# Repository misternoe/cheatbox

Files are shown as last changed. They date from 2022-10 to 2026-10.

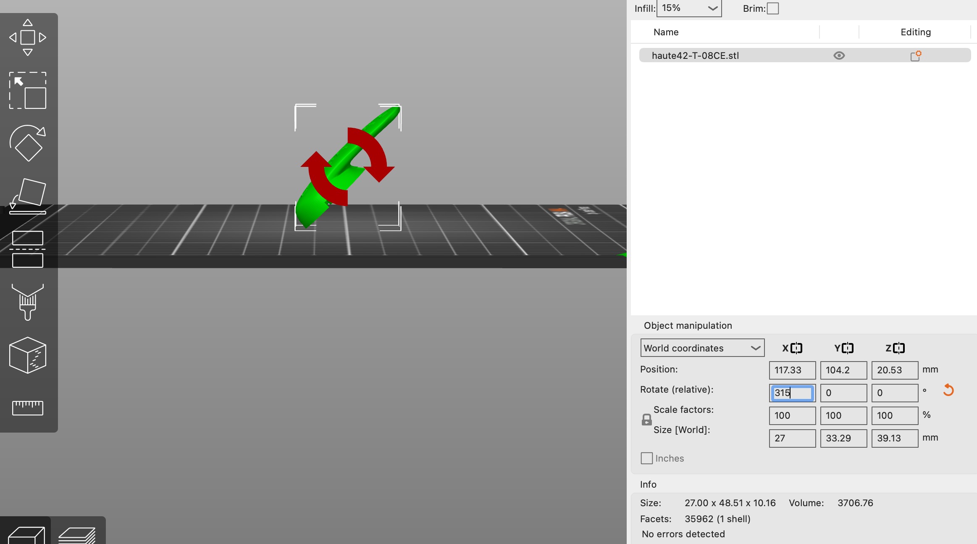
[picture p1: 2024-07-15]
D-BRAKE - Haute42/M and T Series/print-orientation.jpg

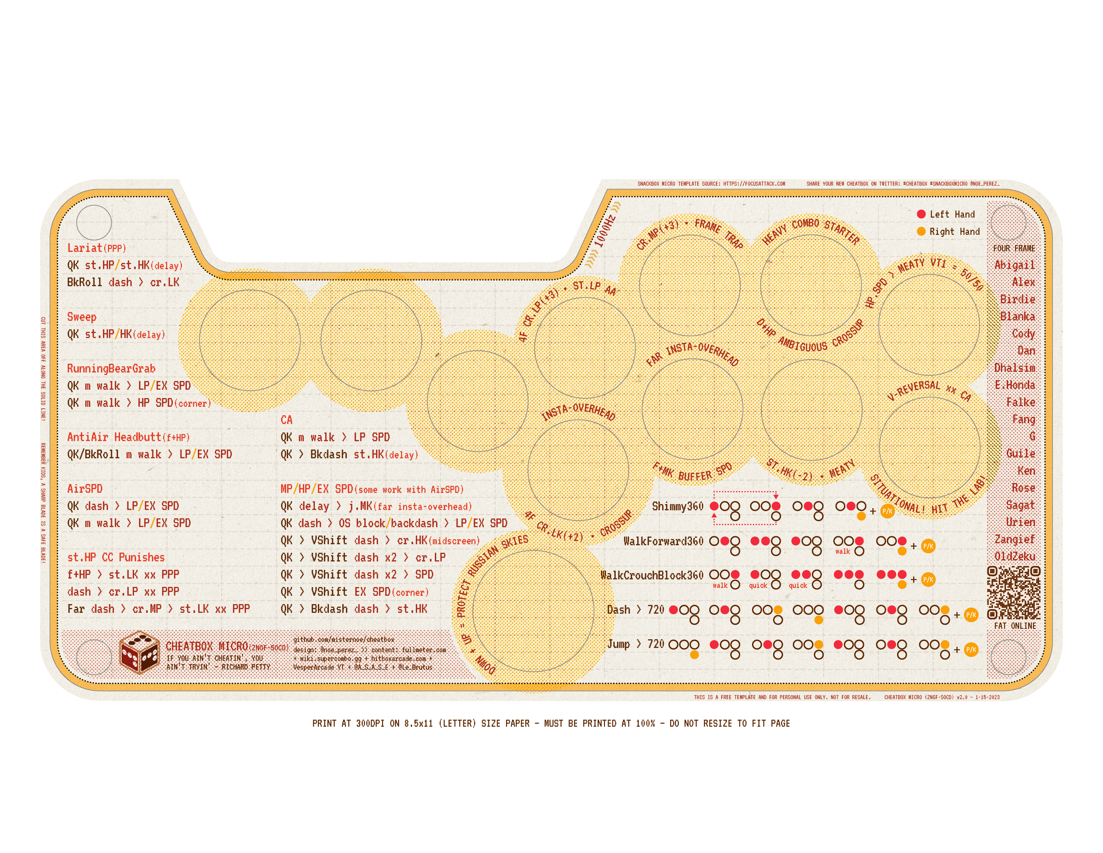
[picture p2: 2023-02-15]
Snackbox Micro/SFV/cheatboxmicro-sfv-zngf-socd-v2-8.5x11-300DPI.png

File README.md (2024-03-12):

# cheatbox
Resources for leverless / all-button controllers (ABCs)

[Follow me on Twitter for new release and character polls](https://twitter.com/noe_perez_)

[CHEATBOX_PROJECT ETSY SHOP](https://cheatboxproject.etsy.com)

New: 6/11/2023 [CHEATBOX_PROJECT // FOOTSIE v2.0](https://twitter.com/noe_perez_/status/1667916644956397570)

New: 6/2/2023 [CHEATBOX_PROJECT // D-BRAKE](https://twitter.com/noe_perez_/status/1664718600328957953)

New: 5/31/2023 [Cheatbox Micro SF6 Juri released!](https://twitter.com/noe_perez_/status/1663921536099598338)
 
New: 5/19/2023 [Cheatbox Micro SF6 Luke released!](https://twitter.com/noe_perez_/status/1659446216063692807)

# About the cheatbox project
- Originally started as a passion project to help all the post-EVO22 hitbox newbies learn their ABCs
- Then Twitter and Hitbox-Gate happened
- Got motivated to help cheatbox users "cheat" harder
- And here we are, making functional meme controllers

[Check out the Mpress Stealth Hype Vid on Twitter](https://twitter.com/noe_perez_/status/1565812427530420225)

# Current line-up
- [Snackbox Micro - GGST_BA](https://twitter.com/noe_perez_/status/1645816619053064195) *Available in 2 layouts!
- [Cheatbox - GGST_BR](https://twitter.com/noe_perez_/status/1638570048884178950)
- [Snackbox Micro - GGST_BR](https://twitter.com/noe_perez_/status/1634728157243637766)

- [Cheatbox Micro - SF6 - Juri](https://twitter.com/noe_perez_/status/1663921536099598338)
- [Cheatbox Micro - SF6 - Kimberly](https://twitter.com/noe_perez_/status/1649158748055785477)
- [Cheatbox Micro - SF6 - Luke](https://twitter.com/noe_perez_/status/1659446216063692807)
- [Cheatbox Micro - SF6 - Ryu](https://twitter.com/noe_perez_/status/1649206253598408705)

- [Snackbox Micro - SFV - GUL](https://twitter.com/noe_perez_/status/1619028822489460736)
- [CheatPress - SFV - JUR](https://twitter.com/noe_perez_/status/1584354839945183232)
- [CheatPress Stealth - SFV - JUR](https://twitter.com/noe_perez_/status/1570083703308574725)
- [Snackbox Micro - SFV - JUR](https://twitter.com/noe_perez_/status/1584354839945183232)
- [Snackbox Micro - SFV - LAR](https://twitter.com/noe_perez_/status/1576731258339864576)
- [CheatPress - SFV - POISON](https://twitter.com/noe_perez_/status/1583488518348677120)
- [Cheatbox - SFV - POISON](https://twitter.com/noe_perez_/status/1583616455249399808)
- [Cheatbox Micro - SFV - POISON](https://twitter.com/noe_perez_/status/1584944122330337283)
- [Cheatbox - SFV - ROXY x POISON](https://twitter.com/noe_perez_/status/1587867720065900549)
- [Cheatbox Micro - SFV - ROXY x POISON](https://twitter.com/noe_perez_/status/1591116780088725504)
- [Snackbox Micro - SFV - ZNGF](https://twitter.com/noe_perez_/status/1573340315867570176)
- [Snackbox Micro - SFV - ZNGF-SOCD](https://twitter.com/noe_perez_/status/1573340315867570176)

- [Snackbox Micro - SG - BGBND](https://twitter.com/noe_perez_/status/1614702423410626562)

- [Snackbox Micro - SOCD - BRBRSHP](https://twitter.com/noe_perez_/status/1570630760545292289)
- [Snackbox Micro - SOCD - ORNGBX](https://twitter.com/noe_perez_/status/1579558010036555776)
- Cheatbox - Hitbox Input Trainer

# Upcoming
- CheatPress - SOCD - Various Colorways
- CheatPress Stealth - SOCD
- CheatPress - GGST_BK
- CheatPress - GGST_BR

- Cheatbox - GGST_BK
- Cheatbox - SFV - DHALSIM
- Cheatbox Micro - SFV - DHALSIM
- Cheatbox Micro - SFV - LUKE

- Cheatbox Micro - GGST_RA
- Cheatbox Micro - GGST_IN
- And some super dumb meme controllers

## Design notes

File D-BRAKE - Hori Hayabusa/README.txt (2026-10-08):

CHEATBOX_PROJECT
D-BRAKE v2.0 for Hori Hayabusa buttons

/////////////
DISCLAIMER
/////////////

Use this product at your own risk. I am not responsible for any damages to you or your property. If you experience any pain or discomfort while using the D-BRAKE, please discontinue use immediately.

/////////////
PRINTER SETTINGS
/////////////

Infill: 10% to 25%

Layer height: 0.2 minimum

Build Plate Adhesion Type: Brim highly recommended due to the verticality of the printing orientation

Supports: Yes - Touching Buildplate

Print orientation: For a standard FDM printer, a 45 to 60 degree angle with the tail of the D-BRAKE facing upward is recommended!

/////////////
INSTALLATION
/////////////
1. Remove plunger or keycap (see manufacturer for info on this if needed)
2. Mount D-BRAKE onto the microswitch

/////////////
REPORT BACK + ENJOY
/////////////

Let me know how you're enjoying this on Twitter or here on GitHub. Constructive feedback is always welcome. Give me a follow on Twitter @noe_perez_ to keep up with other projects like this and new Cheatbox Project designs for the Snackbox Micro, Hit Box, and other all-button controllers.

https://github.com/misternoe/cheatbox

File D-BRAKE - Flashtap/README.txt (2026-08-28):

CHEATBOX_PROJECT
D-BRAKE v2.0 for Flexigear FlashTap Buttons

/////////////
DISCLAIMER
/////////////

Use this product at your own risk. I am not responsible for any damages to you or your property. If you experience any pain or discomfort while using the D-BRAKE, please discontinue use immediately.

/////////////
PRINTER SETTINGS
/////////////

IMPORTANT -- Printing Orientation
The D-BRAKE looks best when printed upright, with the mount parallel to the build plate. Check the reference photo in the GitHub directory.

Infill: 10% to 25%

Layer height: 0.2 minimum

Build Plate Adhesion Type: Brim highly recommended due to the verticality of the printing orientation

Supports: Yes - Touching Buildplate

Print orientation: For a standard FDM printer, a 45 to 60 degree angle with the tail of the D-BRAKE facing upward is recommended!

/////////////
FINISHING
/////////////
If your printer is unable to produce a smooth print, it is recommended to sand down this print to provide a smoother and more comfortable surface. Use a high grit wet sandpaper (600 or higher). Please remember to take proper safety precautions to avoid inhalation by yourself and others in your vicinity.

/////////////
INSTALLATION
/////////////
1. Remove plunger or keycap (see manufacturer for info on this if needed)
2. Mount D-BRAKE onto the button/microswitch

/////////////
REPORT BACK + ENJOY
/////////////

Let me know how you're enjoying this on Twitter or here on GitHub. Constructive feedback is always welcome. Give me a follow on Twitter @noe_perez_ to keep up with other projects like this and new Cheatbox Project designs for the Snackbox Micro, Hit Box, and other all-button controllers.

https://github.com/misternoe/cheatbox

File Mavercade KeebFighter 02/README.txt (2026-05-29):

CHEATBOX_PROJECT
FOOTSIE for Mavercade KeebFighter02

/////////////
DISCLAIMER
/////////////

Use this product at your own risk. I am not responsible for any damages to you or your property.

///////////////////////////////
THINGS TO KNOW BEFORE PRINTING
///////////////////////////////

I have not tested this on an actual controller. All testing was conducted on a printed step file from Mavercade. Assuming I didn't mess up the scaling, this should work fine!

Materials tested:
PLA: Excellent output

Important:
Make sure that your 3D printer is configured properly before printing this accessory. Due to the thin nature of this product, ensuring that the first few layers print cleanly will ensure a stronger end product.

/////////////
PRINTER SETTINGS
/////////////
20% infill or higher recommended

Printing orientation
You can print flat for a faster print, or face down to make use of built plate texture. 

Build Plate Adhesion Type
Mouse ears or brim highly recommended

Supports
Highly recommend use of a support material if printing face down! Printing face up requires no supports, but I would recommend adding support to the screw holes for aesthetics.

/////////////
INSTALLATION
/////////////

USAGE AS A TRAY EXTENDER:
You can simply pop your Keebfighter 02 into the FOOTSIE and your are good to go

OR SCREW IT INTO YOUR CONTROLLER:
Unscrew the bottom screws from the controller and run them through the bottom of the FOOTSIE into the controller. I have not tested this myself, so you may need to get longer screws!

/////////////
REPORT BACK + ENJOY
/////////////

Let me know how testing is going on Twitter or here on GitHub. Give me a follow on Twitter @noe_perez_ to keep up with other projects like this and new Cheatbox Project designs for the Snackbox Micro and other all-button controllers.

https://github.com/misternoe/cheatbox

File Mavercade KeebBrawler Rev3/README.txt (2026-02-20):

CHEATBOX_PROJECT
THUMB NUBS
For Mavercade KeebBrawler Rev3

/////////////
DISCLAIMER
/////////////

Use this product at your own risk. I am not responsible for any damages to you or your property.

/////////////
PRINTER SETTINGS
/////////////

Filament type: PLA not recommended! PETG recommended at a minimum. Black PETG-HF if trying to color match with the stock nylon buttons.

Infill: 80%, Gyroid

Layer Height: 0.16mm minimum

Printing orientation: User preference

Build Plate Adhesion: Glue is recommended for easier removal

Supports: Tree

Note: You may need to do some clean up on the stem mounts to be able to install properly

/////////////
REPORT BACK + ENJOY
/////////////

Let me know how testing is going on Twitter or here on GitHub. Give me a follow on Twitter @cheatboxproject to keep up with other projects like this and new Cheatbox Project designs for the Snackbox Micro, Haute42, and other all-button controllers.

https://github.com/misternoe/cheatbox

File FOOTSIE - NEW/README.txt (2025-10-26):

CHEATBOX_PROJECT
FOOTSIE v2.0
For Snackbox Micro One Piece Case, 2022/2023 Artwork Case, Original Artwork Case

UPDATED 10/26/25 to address mesh issues

/////////////
DISCLAIMER
/////////////

Use this product at your own risk. I am not responsible for any damages to you or your property.

///////////////////////////////
THINGS TO KNOW BEFORE PRINTING
///////////////////////////////

All testing conducted on a Dremel DigiLab 3D45 with a stock 2023 Snackbox Micro One Piece Case, 2023 Artwork Case, and Original Artwork Case

Materials tested:
PLA: Excellent output

Important:
Make sure that your 3D printer is configured properly before printing this accessory. Due to the thin nature of this product, ensuring that the first few layers print cleanly will ensure a stronger end product.

/////////////
PRINTER SETTINGS
/////////////
20% infill or higher recommended

Layer height
0.34 minimum, 0.3 or lower recommended!

Printing orientation
Larger printers can print this flat. Smaller printers will have to rotate it 90 degrees. Please see reference image in this folder.

Build Plate Adhesion Type
Skirt highly recommended if printing either flat or at 90 degrees

Supports
Yes - Touching Buildplate if printing 90 degrees will work. Support everywhere can be a hassle to remove but may prevent warping of the thin baseplate. If printing flat, I do not know, my printer is too small to print this model flat.

/////////////
SIZING (when rotated 90 degrees)
/////////////

FOOTSIE-LEFT
X = 172mm
Y = 17.5mm
Z = 165.25mm

FOOTSIE-RIGHT
X = 165.5mm
Y = 17.5mm
Z = 165.25mm

/////////////
INSTALLATION
/////////////
1. Unscrew backplate of Snackbox Micro Case

2. Attach the left and right pieces together

3. Install The Footsie between backplate and Snackbox Micro Case. The Footsie is to be “sandwiched” between these two components.

4. Insert screws and be sure to not over-tighten

/////////////
REPORT BACK + ENJOY
/////////////

Let me know how testing is going on Twitter or here on GitHub. Give me a follow on Twitter @noe_perez_ to keep up with other projects like this and new Cheatbox Project designs for the Snackbox Micro and other all-button controllers.

https://github.com/misternoe/cheatbox

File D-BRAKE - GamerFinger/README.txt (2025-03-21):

CHEATBOX_PROJECT
D-BRAKE v1.0 for GamerFinger Buttons

/////////////
DISCLAIMER
/////////////

Use this product at your own risk. I am not responsible for any damages to you or your property. If you experience any pain or discomfort while using the D-BRAKE, please discontinue use immediately.

///////////////////////////////
COMPATIBILITY
///////////////////////////////

GamerFinger Snap-in and Screw-in Buttons
Paradise Arcade MPress (not compatible with the MPress Nano!)
Seimitsu Alutimo

/////////////
PRINTER SETTINGS
/////////////

IMPORTANT -- Printing Orientation
The D-BRAKE looks best when printed upright, with the mount parallel-ish to the build plate. Check the reference photo in the GitHub directory.

Infill: 10% to 25%

Layer height: 0.2 minimum

Build Plate Adhesion Type: Brim highly recommended due to the verticality of the printing orientation

Supports: Yes - Touching Buildplate

/////////////
PRINTING SERVICES: SIZING WHEN UPLOADED
/////////////

TBD

/////////////
INSTALLATION
/////////////
1. Remove plunger or keycap (see manufacturer for info on this if needed)
2. Mount D-BRAKE onto the button/microswitch

Note: if you notice that the D-BRAKE doesn't pop back up when released, you may need to trim down walls of the stem mount. Excess filament can accumulate in this area due to poor bridging and support material.

/////////////
REPORT BACK + ENJOY
/////////////

Let me know how you're enjoying this on Twitter or here on GitHub. Constructive feedback is always welcome. Give me a follow on Twitter @CheatboxProject to keep up with other projects like this 

https://github.com/misternoe/cheatbox

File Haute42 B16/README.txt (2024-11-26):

CHEATBOX_PROJECT
B16 FACEPLATE v1.0
For Haute42 B16

/////////////
DISCLAIMER
/////////////
This is not intended to be a replacement for the stock faceplate! It stacks on top of the stock plate. 

Use this product at your own risk. I am not responsible for any damages to you or your property.

/////////////
PRINTER SETTINGS
/////////////

Filament type: PLA not recommended! PETG recommended at a minimum. TPU also works great for this.

Infill: 100%

Layer Height: 0.16mm minimum

Printing orientation: User preference
Note: printing face down is recommended to get surface texture on the top surface. Separate files for face up and down printing included.

Build Plate Adhesion: Glue is recommended for easier removal

Supports: None

/////////////
INSTALLATION
/////////////
1. Remove screws from B16

2. Remove all oversized keycaps

3. Install printed faceplate on top of stock faceplate. Note: This is not intended to be a replacement for the stock faceplate!

4. Reinstall screws, that's it.

/////////////
REPORT BACK + ENJOY
/////////////

Let me know how testing is going on Twitter or here on GitHub. Give me a follow on Twitter @cheatboxproject to keep up with other projects like this and new Cheatbox Project designs for the Snackbox Micro, Haute42, and other all-button controllers.

https://github.com/misternoe/cheatbox

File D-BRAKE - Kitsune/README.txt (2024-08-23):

CHEATBOX_PROJECT
D-BRAKE v1.0

/////////////
DISCLAIMER
/////////////

Use this product at your own risk. I am not responsible for any damages to you or your property. If you experience any pain or discomfort while using the D-BRAKE, please discontinue use immediately.

///////////////////////////////
THINGS TO KNOW BEFORE PRINTING
///////////////////////////////

All testing conducted on a Bambu X1C with Prusa Galaxy Black PETG and Bambu PETG-HF

/////////////
PRINTER SETTINGS
/////////////

IMPORTANT -- Printing Orientation
The D-BRAKE looks best when printed upright with a 20º - 30º tilt (D-BRAKE logo facing up) and using regular supports.

Infill: 20% minimum

Layer height: 0.2 minimum

Build Plate Adhesion Type: Brim highly recommended due to the verticality of the printing orientation

Supports: Yes - Touching Buildplate

/////////////
FINISHING (Completely optional or even unnecessary for higher-end printers)
/////////////
It is recommended to sand down this print to provide a smoother and more comfortable surface. Use a high grit wet sandpaper (600 or higher). Please remember to take proper safety precautions to avoid inhalation by yourself and others in your vicinity.

/////////////
PRINTING SERVICES: SIZING WHEN UPLOADED
/////////////

KITSUNE 08mm CE
27.45 × 49.05 × 8.98mm

/////////////
INSTALLATION
/////////////
1. Remove plunger or keycap (see manufacturer for info on this if needed)
2. Mount D-BRAKE onto the button/microswitch (note: if you encounter resistance, you may need to shave off some excess filament from the stem)
3. Enjoy!

/////////////
REPORT BACK + ENJOY
/////////////

Let me know how you're enjoying this on Twitter or here on GitHub. Constructive feedback is always welcome. Give me a follow on Twitter @noe_perez_ to keep up with other projects like this and new Cheatbox Project designs for the Snackbox Micro, Hit Box, and other all-button controllers.

https://github.com/misternoe/cheatbox

/////////////
SHOUTOUTS
/////////////

@junkfoodarcades for making great products supporting the modding community

@NoGoodCitizen for spreading the gospel of the Cheatbox_Project to the FGC

Robear512 (@236Robear) for their dedication to bringing a Qanba Gravity D-BRAKE

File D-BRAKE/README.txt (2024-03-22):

CHEATBOX_PROJECT
D-BRAKE v1.0

/////////////
DISCLAIMER
/////////////

Use this product at your own risk. I am not responsible for any damages to you or your property. If you experience any pain or discomfort while using the D-BRAKE, please discontinue use immediately.

///////////////////////////////
THINGS TO KNOW BEFORE PRINTING
///////////////////////////////

All testing conducted on a Dremel DigiLab 3D45

Materials tested:
PLA: Excellent output

/////////////
PRINTER SETTINGS
/////////////

IMPORTANT -- Printing Orientation
The D-BRAKE looks best when printed upright, with the mount parallel to the build plate. Check the reference photo in the GitHub directory.

Infill: 10% recommended to keep the weight down

Layer height: 0.2 minimum

Build Plate Adhesion Type: Brim highly recommended due to the verticality of the printing orientation

Supports: Yes - Touching Buildplate

/////////////
FINISHING
/////////////
It is recommended to sand down this print to provide a smoother and more comfortable surface. Use a high grit wet sandpaper (600 or higher). Please remember to take proper safety precautions to avoid inhalation by yourself and others in your vicinity.

/////////////
NOTE ON KAILH CHOC V1 VERSIONS
/////////////
Printing the original is recommended. A version with a thicker stem is available and will have a tighter fit, but it can actually pop out easier in my experience. Your mileage may vary.

/////////////
HOME PRINTING: SIZING WHEN ORIENTED PROPERLY (X= -90 degrees, Y=15 degrees. (-25 degrees recommended for Quanta Gravity)
/////////////

KAILH CHOC V1
X = 21.5654mm
Y = 14mm
Z = 51.0312mm

CHERRY MX - SIZE 10
X = 21.4597mm
Y = 16mm
Z = 51.0636mm

CHERRY MX - SIZE 11
X = 21.5962mm
Y = 16.9823mm
Z = 51.3884mm

SANWA/SEIMITSU 24mm — SIZE 10
X = 21.5717mm
Y = 23.25mm
Z = 50.9989mm

SANWA/SEIMITSU 24mm — SIZE 10 - KRAKD
X = 21.4273mm
Y = 23.25mm
Z = 50.9989mm

SANWA/SEIMITSU 24mm — SIZE 11
X = 21.5567mm
Y = 24.25mm
Z = 50.9989mm

SANWA/SEIMITSU 30mm - Size 10
X = 24.5023mm
Y = 23.25mm
Z = 52.3357mm

SANWA/SEIMITSU 30mm - Size 11
X = 24.4463mm
Y = 24.25mm
Z = 52.3357mm

GRAVITY REMIX-CHEATBOX-PROJECT 24mm — Size 11
X = 24.91mm
Y = 22.88mm
Z = 47.03mm

GRAVITY REMIX-CHEATBOX-PROJECT 30mm — Size 11
X = 26.43mm
Y = 31.62mm
Z = 46.21mm

GRAVITY REMIX-ROBEAR512 30mm (~Size 20)
X = 26.77mm
Y = 42.33mm
Z = 45.56mm

/////////////
PRINTING SERVICES: SIZING WHEN UPLOADED
/////////////

KAILH CHOC V1
24.92 × 50.5 × 13.93mm

KAILH CHOC V1 - THICKER STEM
24.92 × 50.5 × 13.93mm

CHERRY MX - SIZE 10
24.92 × 50.5 × 15.99mm

CHERRY MX - SIZE 11
24.92 × 50.5 × 16.9mm

SANWA/SEIMITSU 24mm - SIZE 10
24.92 × 50.5 × 23.14mm

SANWA/SEIMITSU 24mm - SIZE 10 - KRAKD
24.92 × 50.5 × 23.14mm

SANWA/SEIMITSU 24mm - SIZE 11
24.92 × 50.5 × 24.13mm

SANWA/SEIMITSU 30mm - SIZE 10
26.78 × 51.72 × 23.14mm

SANWA/SEIMITSU 30mm - SIZE 11
26.78 × 51.72 × 24.13mm

GRAVITY REMIX-CHEATBOX-PROJECT 24mm — SIZE 11
24.91 × 50.32 × 18.83mm

GRAVITY REMIX-CHEATBOX-PROJECT 30mm — SIZE 11
26.43 × 51.96 × 19.83mm

GRAVITY REMIX-ROBEAR512 30mm
26.77 × 51.71 × 31.64mm

/////////////
INSTALLATION
/////////////
1. Remove plunger or keycap (see manufacturer for info on this if needed)
2. Mount D-BRAKE onto the button/microswitch
3. Rotate button to adjust angle of D-BRAKE (note: this does not apply to devices where switches are mounted directly to a PCB, such as the Snackbox Micro, Flatbox, Keybox, etc)

/////////////
REPORT BACK + ENJOY
/////////////

Let me know how you're enjoying this on Twitter or here on GitHub. Constructive feedback is always welcome. Give me a follow on Twitter @noe_perez_ to keep up with other projects like this and new Cheatbox Project designs for the Snackbox Micro, Hit Box, and other all-button controllers.

https://github.com/misternoe/cheatbox

/////////////
SHOUTOUTS
/////////////

@junkfoodarcades for making great products supporting the modding community

@NoGoodCitizen for spreading the gospel of the Cheatbox_Project to the FGC

Robear512 (@236Robear) for their dedication to bringing a Qanba Gravity D-BRAKE

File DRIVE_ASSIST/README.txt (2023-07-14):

CHEATBOX_PROJECT
DRIVE_ASSIST v1.0

/////////////
DISCLAIMER
/////////////

Use this product at your own risk. I am not responsible for any damages to you or your property. If you experience any pain or discomfort while using the DRIVE_ASSIST, please discontinue use immediately.

///////////////////////////////
THINGS TO KNOW BEFORE PRINTING
///////////////////////////////

All testing conducted on a Dremel DigiLab 3D45

Materials tested:
PETG: Excellent output

/////////////
PRINTER SETTINGS
/////////////

IMPORTANT -- Printing Orientation
The DRIVE_ASSIST looks best when printed with a 60 degree tilt no the y axis.

Infill: 10% recommended to keep the weight down

Layer height: 0.2 minimum

Other Walls/Shells: 3 minimum

Build Plate Adhesion Type: Brim highly recommended due to the verticality of the printing orientation

Supports: Yes - Touching Buildplate

/////////////
FINISHING
/////////////
It is recommended to sand down this print to provide a smoother and more comfortable surface. Use a high grit wet sandpaper (600 or higher). Please remember to take proper safety precautions to avoid inhalation by yourself and others in your vicinity.

/////////////
HOME PRINTING: SIZING WHEN ORIENTED PROPERLY (X= 60 degrees)
/////////////

SANWA/SEIMITSU 30mm
X = 29.6091mm
Y = 33.3088mm
Z = 34.4562mm

/////////////
PRINTING SERVICES: SIZING WHEN UPLOADED
/////////////

SANWA/SEIMITSU 30mm
29.61 × 29.61 × 23.51mm

/////////////
INSTALLATION
/////////////
1. Remove plunger or keycap (see manufacturer for info on this if needed)
2. Mount DRIVE_ASSIST onto the button/microswitch
3. Rotate button to adjust angle of DRIVE_ASSIST

/////////////
REPORT BACK + ENJOY
/////////////

Let me know how you're enjoying this on Twitter or here on GitHub. Constructive feedback is always welcome. Give me a follow on Twitter @noe_perez_ to keep up with other projects like this and new Cheatbox Project designs for the Snackbox Micro, Hit Box, and other all-button controllers.

https://github.com/misternoe/cheatbox

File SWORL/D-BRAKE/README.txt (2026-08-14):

CHEATBOX_PROJECT
D-BRAKE v2.0 for Junkfood Custom Arcades SWORL Controller

/////////////
DISCLAIMER
/////////////

Use this product at your own risk. I am not responsible for any damages to you or your property. If you experience any pain or discomfort while using the D-BRAKE, please discontinue use immediately.

///////////////////////////////
THINGS TO KNOW BEFORE PRINTING
///////////////////////////////

All testing conducted on a SWORL Basic (Launch Model)

All test printing with a Bambu X1 Carbon

Materials tested:
PETG: Excellent output

/////////////
PRINTER SETTINGS
/////////////

IMPORTANT -- Printing Orientation
The D-BRAKE looks best when printed upright, with the mount parallel to the build plate. Check the reference photo in the GitHub directory.

Infill: 10% to 25%

Layer height: 0.2 minimum

Build Plate Adhesion Type: Brim highly recommended due to the verticality of the printing orientation

Supports: Yes - Touching Buildplate

/////////////
INSTALLATION
/////////////
1. Remove keycap (see manufacturer for info on this if needed)
2. Mount D-BRAKE onto the button/microswitch

/////////////
REPORT BACK + ENJOY
/////////////

Let me know how you're enjoying this on Twitter or here on GitHub. Constructive feedback is always welcome. Give me a follow on Twitter @noe_perez_ to keep up with other projects like this and new Cheatbox Project designs for the Snackbox Micro, Hit Box, and other all-button controllers.

https://github.com/misternoe/cheatbox

/////////////
SHOUTOUTS
/////////////

@junkfoodarcades for making great products supporting the modding community

@NoGoodCitizen for spreading the gospel of the Cheatbox_Project to the FGC

Robear512 (@236Robear) for their dedication to bringing us a Qanba Gravity D-BRAKE

@brainpipeFGC for the idea to explore and workshop the potential of the D-BRAKE + G16

Anyone's that supported my on etsy or spread the word about cheatbox_project products!

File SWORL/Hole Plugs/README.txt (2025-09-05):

CHEATBOX_PROJECT
HOLE PLUGS
For Junkfood Arcade SWORL

/////////////
DISCLAIMER
/////////////
This is not intended to be a replacement for the stock faceplate! It stacks on top of the stock plate. 

Use this product at your own risk. I am not responsible for any damages to you or your property.

/////////////
PRINTER SETTINGS
/////////////

Filament type: TPU only! Harder materials risk cosmetic damage to the finish of your controller!

Infill: Gyroid, 40%

Layer Height: 0.2mm minimum

Printing orientation: Print face down

Build Plate Adhesion: Glue is recommended for easier removal

Supports: None

/////////////
INSTALLATION
/////////////
Above Artwork Version:
Acrylic top plate should be on. Carefully push down into place

Below Artwork Version:
Remove artwork then push into hole

/////////////
REPORT BACK + ENJOY
/////////////

Let me know how testing is going on Twitter or here on GitHub. Give me a follow on Twitter @cheatboxproject to keep up with other projects like this and new Cheatbox Project designs for the Snackbox Micro, Haute42, and other all-button controllers.

https://github.com/misternoe/cheatbox

Check out my Etsy shop at cheatboxproject.etsy.com

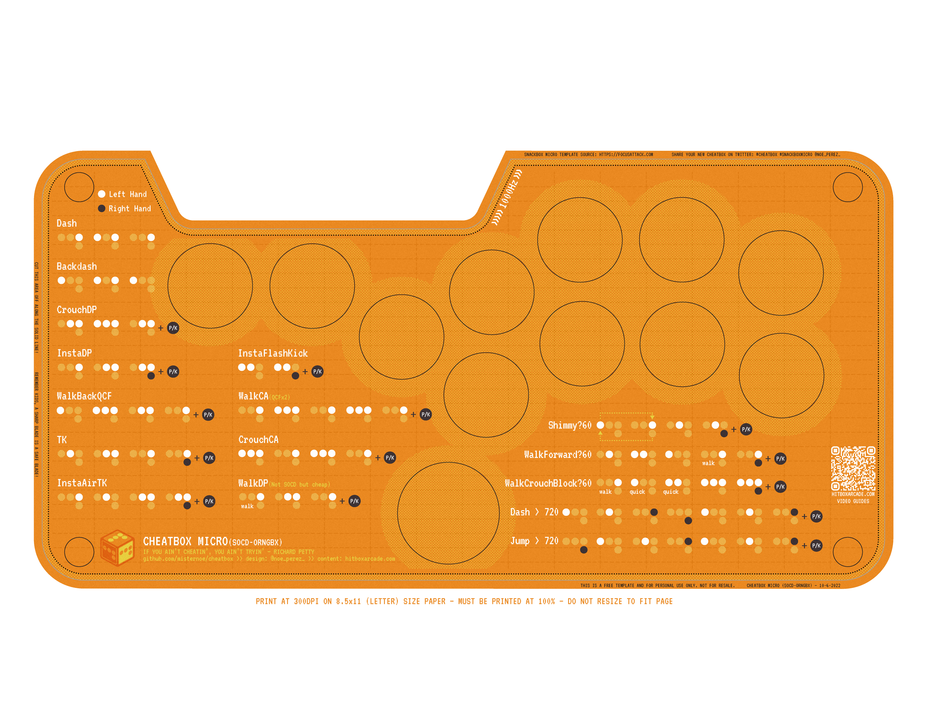
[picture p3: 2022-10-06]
Snackbox Micro/SOCD/cheatboxmicro-socd-orngbx-8.5x11-300DPI.png

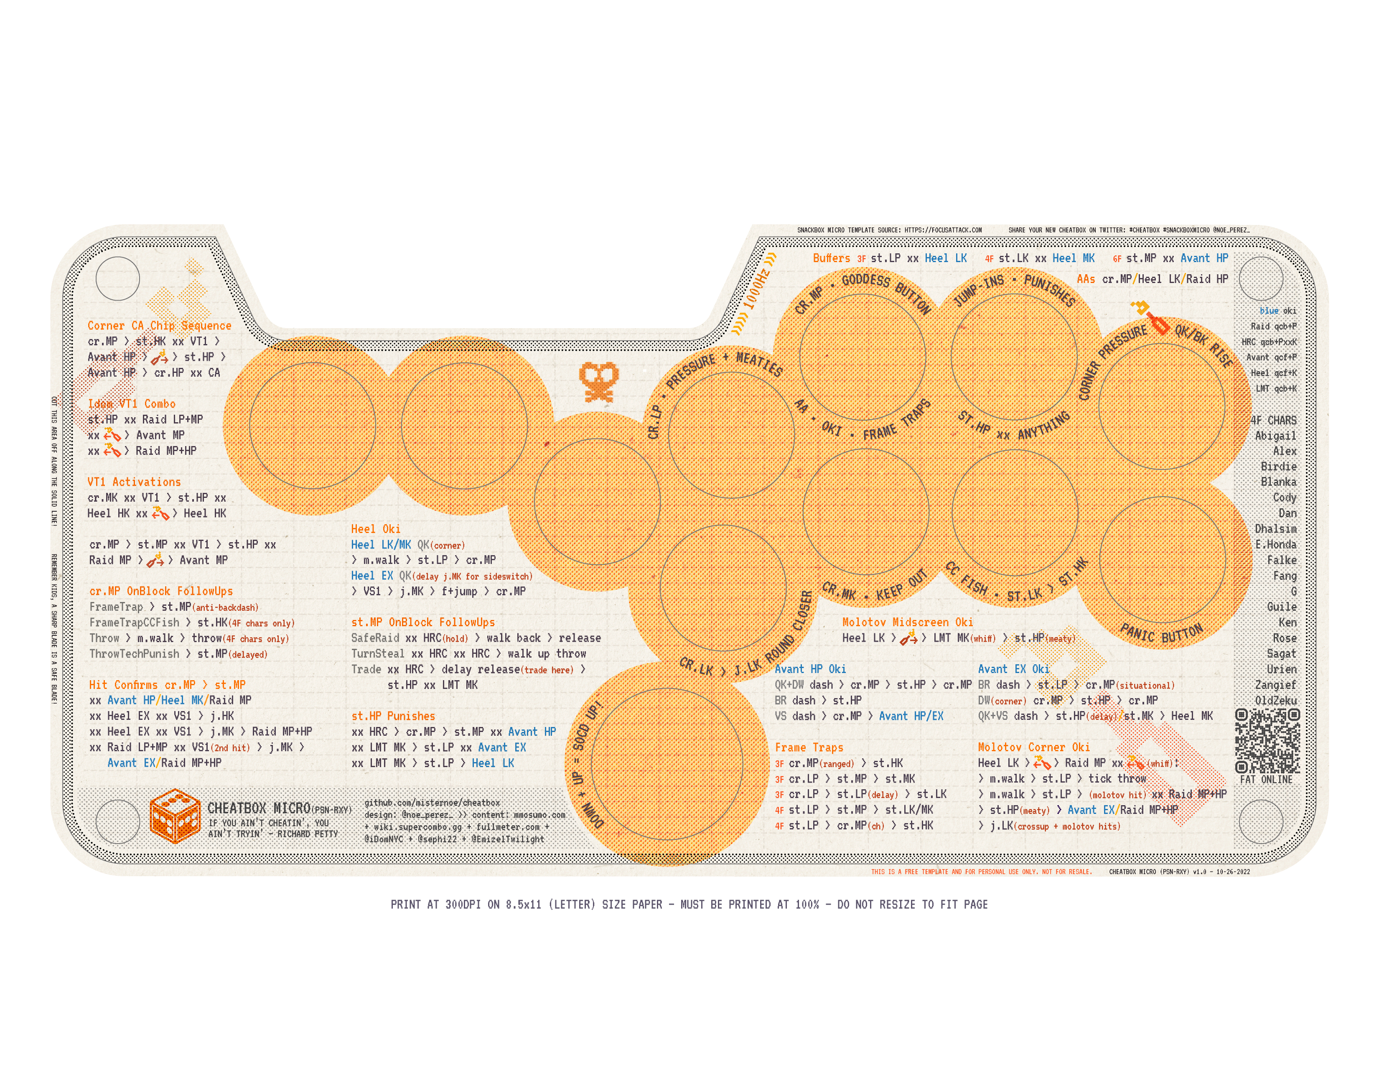
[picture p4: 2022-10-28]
Snackbox Micro/SFV/cheatboxmicro-sfv-psn-rxy-8.5x11-300DPI.png

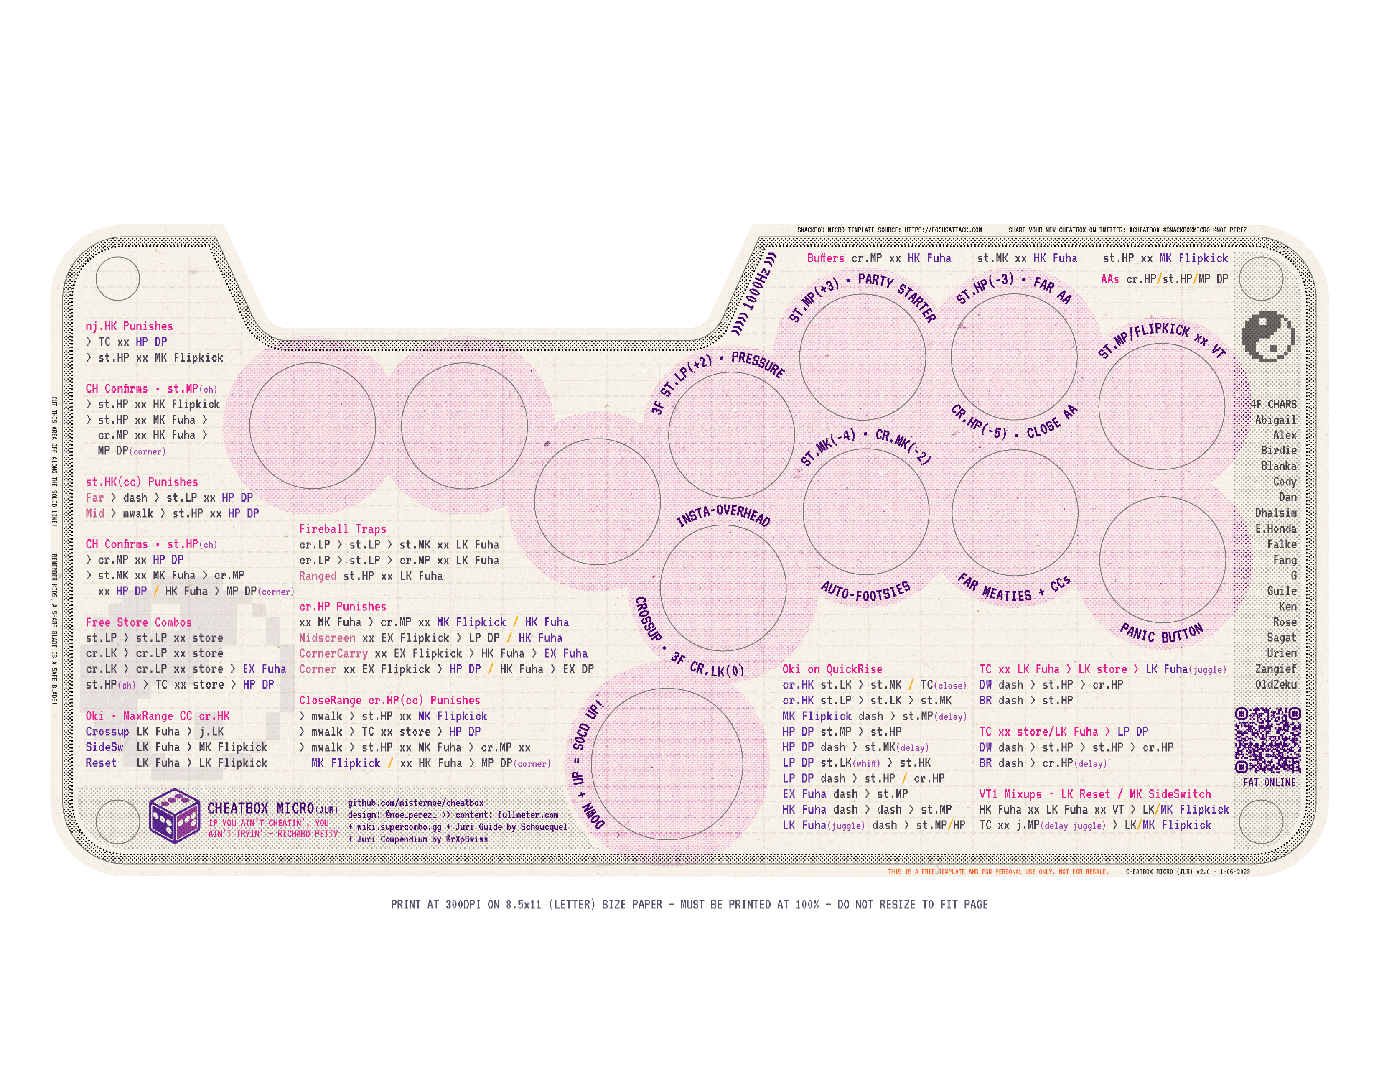
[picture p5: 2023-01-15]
Snackbox Micro/SFV/cheatboxmicro-sfv-jur-v2-8.5x11-300DPI.png

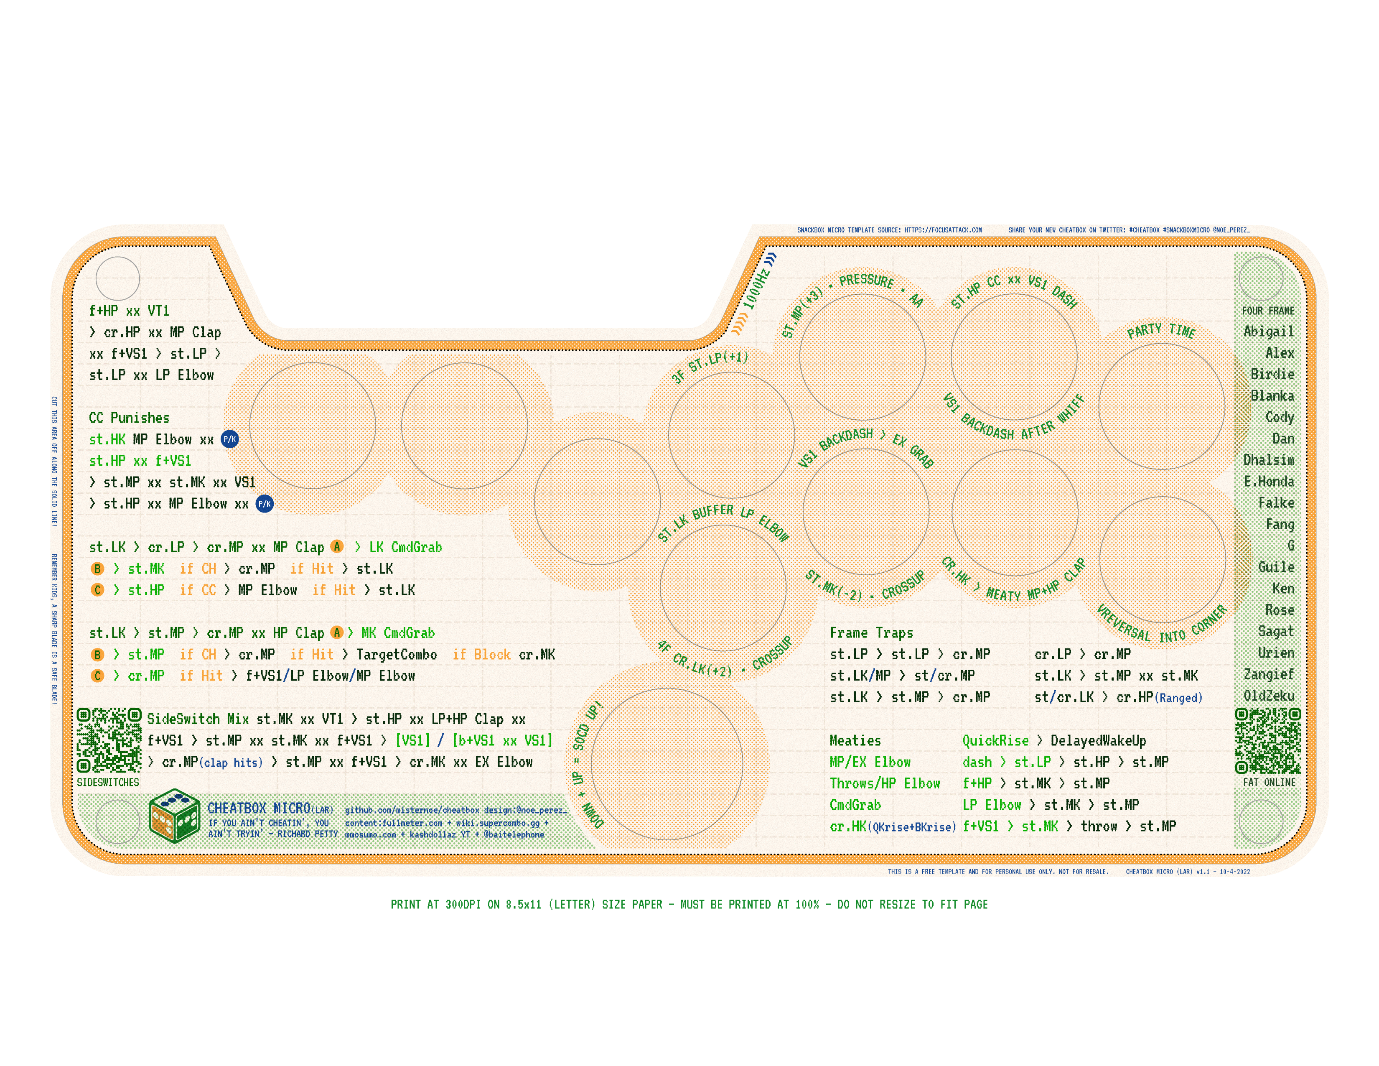
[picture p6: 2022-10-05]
Snackbox Micro/SFV/cheatboxmicro-sfv-laura-8.5x11-300DPI.png

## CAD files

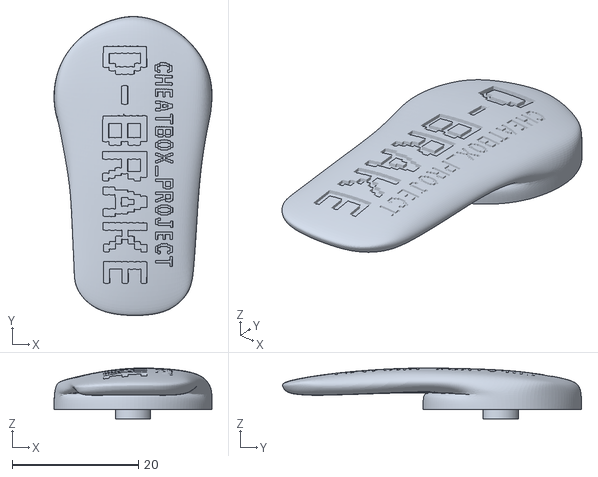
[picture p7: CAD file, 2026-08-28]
D-BRAKE - Flashtap/dbrake-flashtap30-08mm-CE.stl
25.0 x 47.3 x 8.05

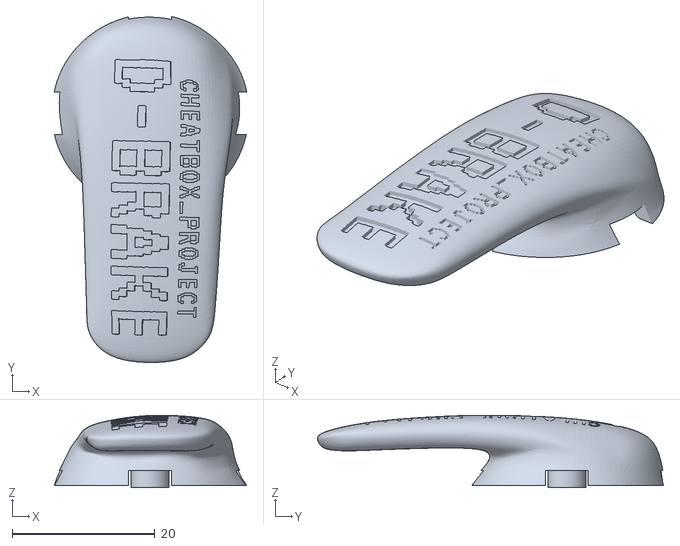
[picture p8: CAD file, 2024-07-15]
D-BRAKE - Haute42/M and T Series/haute42-MT-08CE.stl
27.0 x 48.5 x 10.2

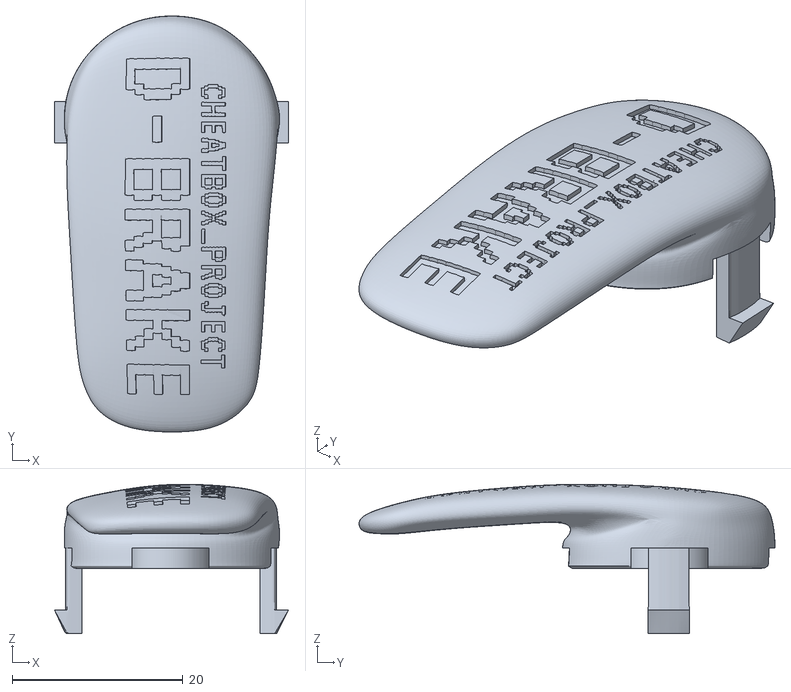
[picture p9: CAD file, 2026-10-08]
D-BRAKE - Hori Hayabusa/dbrake-hayabusa-30mm-8.5mm-CE.stl
27.4 x 48.7 x 17.5

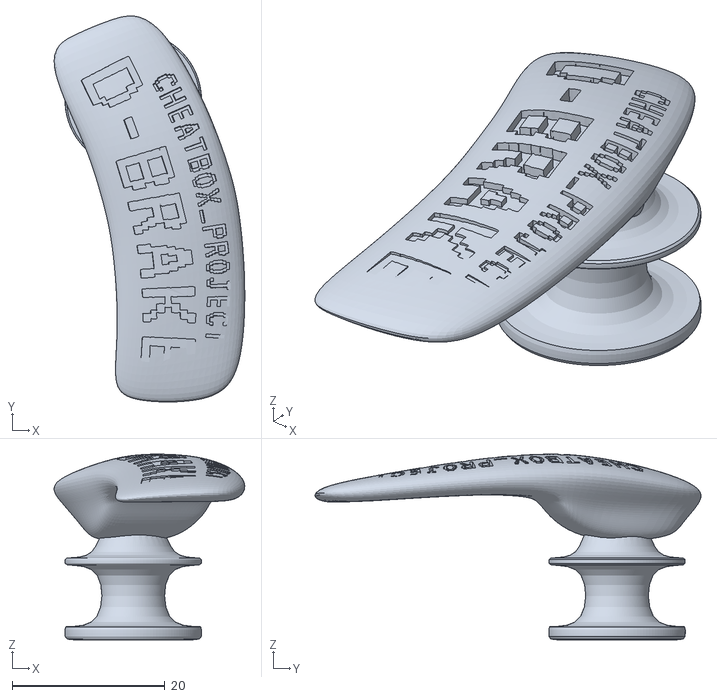
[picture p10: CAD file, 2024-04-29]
D-BRAKE/cheatbox-project-dbrake-sanwa-seimitsu-24mm-size11.stl
24.9 x 50.5 x 24.3

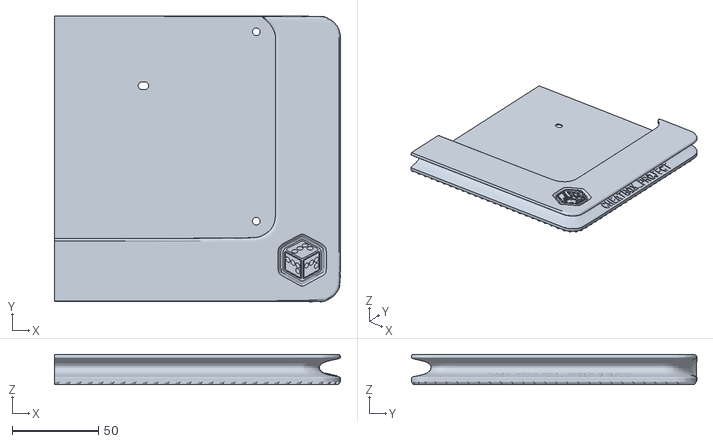
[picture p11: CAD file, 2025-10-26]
FOOTSIE - NEW/cheatbox-project-footsie-right.stl
165.4 x 165.1 x 17.5

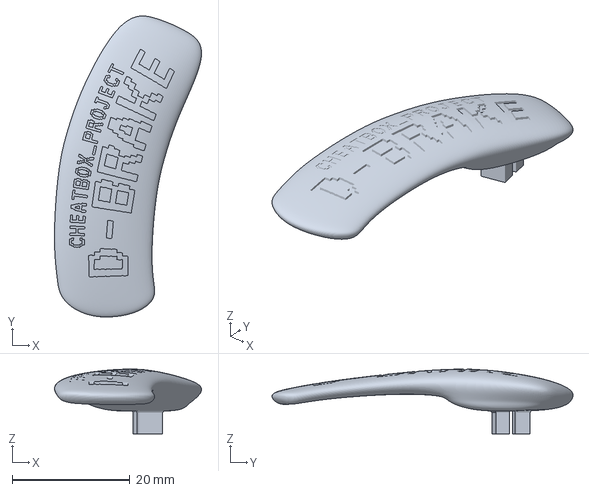
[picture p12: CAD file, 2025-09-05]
Haute42 B16/cheatboxproject-B16-faceplate-fortnite-festival.3mf
24.9 x 51.0 x 11.0 mm

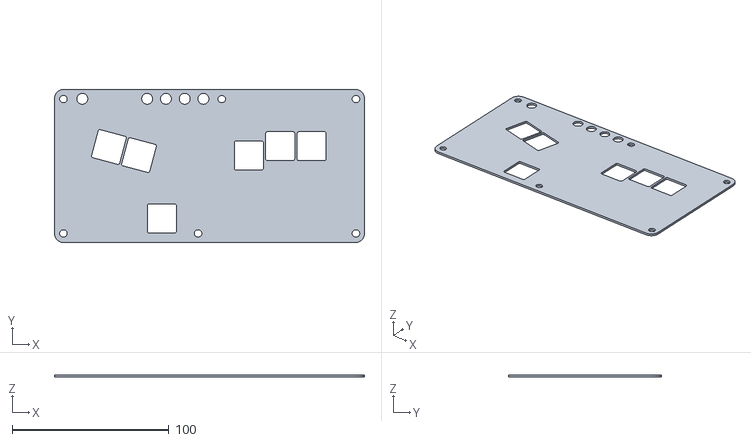
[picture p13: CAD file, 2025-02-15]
Haute42 B16/Fortnite Festival/cheatboxproject-B16-festplate.stl
198.0 x 98.0 x 1.46

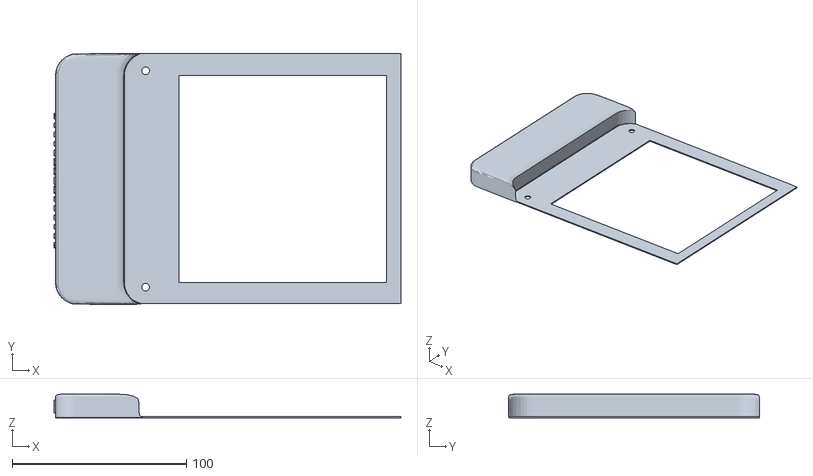
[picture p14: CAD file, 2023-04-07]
Snackbox Micro/ACCESSORIES/FOOTSIE/FOOTSIE - ORIGINAL/Micro XL/micro-xl-footsie-left.stl
199.3 x 143.9 x 13.6

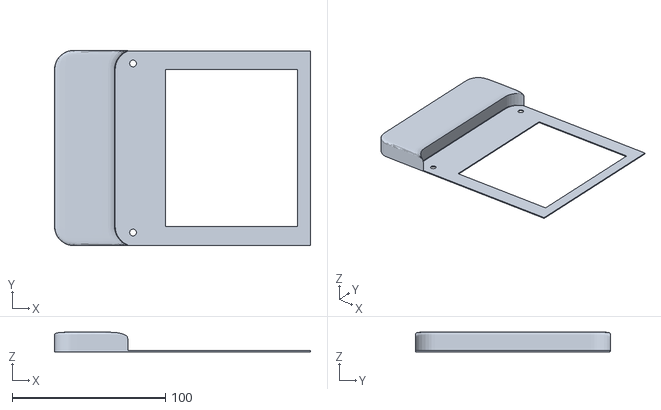
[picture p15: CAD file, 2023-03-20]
Snackbox Micro/ACCESSORIES/FOOTSIE/FOOTSIE - ORIGINAL/Needs Testing/OG Snackbox Micro/og-micro-eco-footsie-left-test-v1.stl
167.0 x 127.4 x 12.8

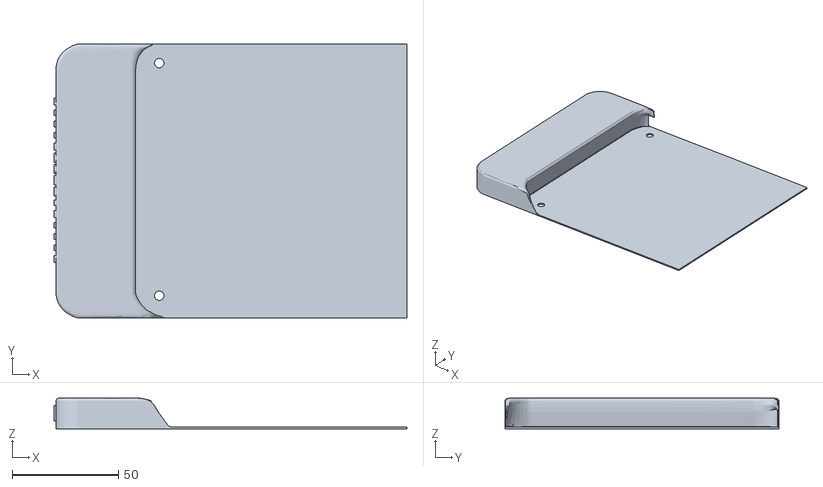
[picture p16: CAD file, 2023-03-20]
Snackbox Micro/ACCESSORIES/FOOTSIE/FOOTSIE - ORIGINAL/New Artwork Case and One Piece Case/onepiececase-footsie-left.stl
166.2 x 129.1 x 14.5

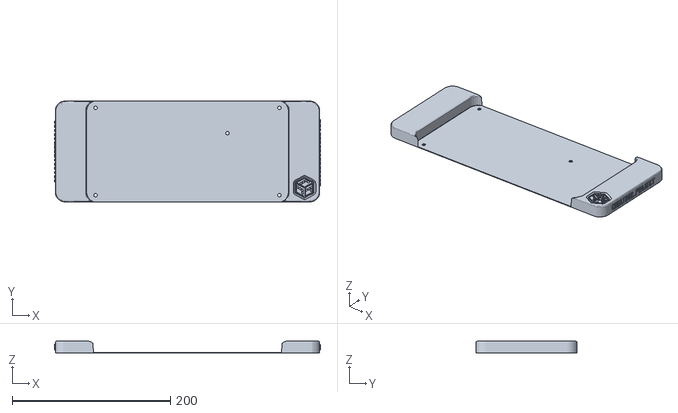
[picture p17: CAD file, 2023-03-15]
Snackbox Micro/ACCESSORIES/FOOTSIE/Original Artwork Case/original-artworkcase-footsie-single.stl
336.1 x 127.4 x 15.1

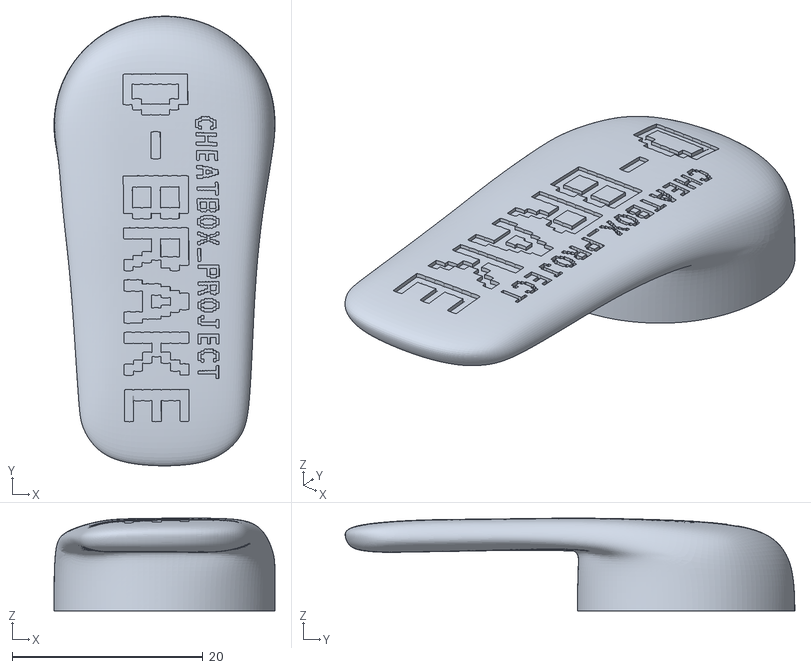
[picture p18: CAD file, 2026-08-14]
SWORL/D-BRAKE/dbrake-sworl-07mm.stl
23.2 x 47.2 x 9.73

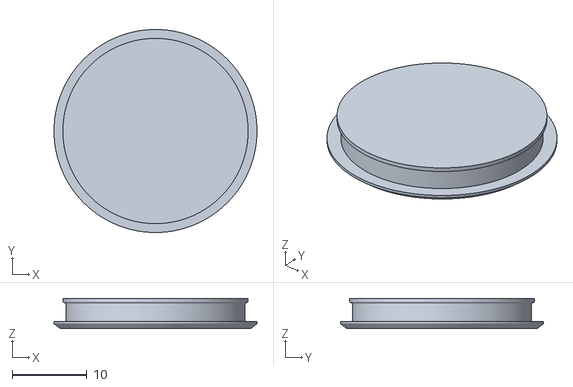
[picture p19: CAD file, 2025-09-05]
SWORL/Hole Plugs/sw-plug-above-artwork.stl
27.2 x 27.2 x 4.05

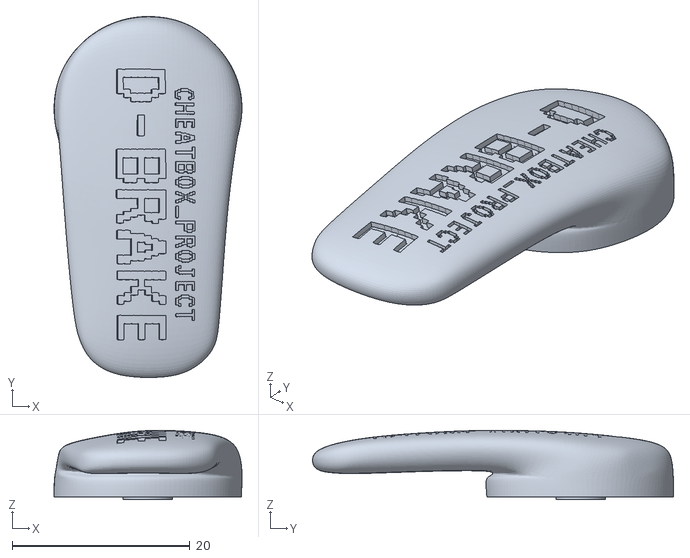
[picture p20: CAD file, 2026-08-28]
D-BRAKE - Flashtap/dbrake-flashtap24-08mm-CE.stl
21.1 x 40.6 x 7.78

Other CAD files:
D-BRAKE/remix-cheatbox-project-dbrake-qanba-gravity-24mm-size11.stl
FOOTSIE - NEW/cheatbox-project-footsie-left.stl
Haute42 B16/cheatboxproject-B16-faceplate-face-up.stl
Snackbox Micro/ACCESSORIES/FOOTSIE/FOOTSIE - ORIGINAL/Micro XL/micro-xl-footsie-right.stl
D-BRAKE - Flashtap/dbrake-flashtap24-09mm-CE.stl
D-BRAKE/cheatbox-project-dbrake-cherrymx-10mm.stl
D-BRAKE/cheatbox-project-dbrake-cherrymx-11mm.stl
D-BRAKE/cheatbox-project-dbrake-sanwa-seimitsu-30mm-size10.stl
D-BRAKE/cheatbox-project-dbrake-sanwa-seimitsu-30mm-size11.stl
D-BRAKE/cheatbox-project-dbrake-snackboxmicro-kailh-choc-v1-thickerstem.stl
D-BRAKE/cheatbox-project-dbrake-snackboxmicro-kailh-choc-v1.stl
D-BRAKE/remix-cheatbox-project-dbrake-qanba-gravity-30mm-size11.stl
D-BRAKE/remix-robear512-dbrake-qanba-gravity-30mm.stl
Haute42 B16/cheatboxproject-B16-faceplate-face-down.stl
SWORL/Hole Plugs/sw-plug-below-artwork.stl
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

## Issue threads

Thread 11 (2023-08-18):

FEATURE REQUEST: allow D-Brake's handle to be adjusted / rotate

cheuksing, 2023-08-18:
### The Issue
Sometimes buttons angle are fixed, and the D BRAKE handle may pointing to a wierd angle.
For example,
1. In enclosure that use snap-in buttons, the snap things avoids a button to be freely rotate. One example is Qanba crystal fightstick.
    - this is a pic from focus attack of its artwork print, you can see the button cutout are not perfect circle.
    - https://focusattack.com/artwork-print-and-cut-for-qanba-crystal-q2-glow/
2. In keyboard-like controller, where the keyboard switches directly attach to the pcb, can't rotate
### Suggestion
Split the handle and bottom part of D-BRAKE into 2 parts, and connect them with a standard fastener.

This allow
1. adjust it to their personal preference or fit their own stick.
2. easier to support more switches / buttons. We only need to create the bottom part, all handles can be shared and reuse.

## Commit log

2023-03-13 FOOTSIE 1.0 Added
    [original-artworkcase-footsie-left.stl, original-artworkcase-footsie-right.stl, original-artworkcase-footsie-single.stl]
2023-03-15 Fixed scale issue
    Dimensions also added to README.txt
    [original-artworkcase-footsie-left.stl, original-artworkcase-footsie-right.stl, original-artworkcase-footsie-single.stl]
2023-03-15 OG Micro (Beta) Added
    [og-micro-footsie-left-test-v1.stl, og-micro-footsie-right-test-v1.stl]
2023-03-15 Tweak to middle screw placement
    [og-micro-footsie-right-test-v1.stl]
2023-03-16 Height adjustments
    1mm height increase
    [og-micro-footsie-left-test-v1.stl, og-micro-footsie-right-test-v1.stl]
2023-03-19 One Piece Case added
    [og-micro-footsie-left.stl, og-micro-footsie-right.stl, onepiececase-footsie-left.stl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]
2023-03-20 1mm tweak to left piece
    Attempting to lessen the center gap between pieces
    [onepiececase-footsie-left.stl]
2023-03-20 1mm adjustment to left screw holes
    [onepiececase-footsie-left.stl]
2023-04-07 Footsie for Micro XL added
    [micro-xl-footsie-left.stl, micro-xl-footsie-right.stl]
2023-04-28 Revisions to Oki
    Added more details to denote whiffs, juggles, and denjin charge usage
2023-04-28 Revisions to Oki section
    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
2023-04-28 Revision to Oki
    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
2023-04-28 Revision to Oki and Swag Combo
    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
2023-05-26 D-BRAKE - KAILH CHOC V1 added
    [cheatbox-project-dbrake-snackboxmicro-kailh-choc-v1.stl]
2023-05-29 D-BRAKE Cherry MX added
    [cheatbox-project-dbrake-cherrymx-10mm.stl, cheatbox-project-dbrake-cherrymx-11mm.stl]
2023-06-02 D-BRAKE for Sanwa and Seimetsu
    [cheatbox-project-dbrake-sanwa-seimetsu-24mm-size10.stl, cheatbox-project-dbrake-sanwa-seimetsu-24mm-size11.stl, cheatbox-project-dbrake-sanwa-seimetsu-30mm-siz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]
2023-06-03 Content updates
    [cheatbox-project-dbrake-sanwa-seimitsu-24mm-size10.stl, cheatbox-project-dbrake-sanwa-seimitsu-24mm-size11.stl, cheatbox-project-dbrake-sanwa-seimitsu-30mm-siz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]
2023-06-07 Micro updates
    - changed Drive Reversal input from HP+HK to f.HP+HK
    - fixed a typo on Luke's frame data (nothing changed from the previous design!)
2023-06-09 sdb202 testing
    [cheatbox-project-dbrake-crown-sdb202-24mm-size11-versionA.stl, cheatbox-project-dbrake-crown-sdb202-24mm-size11-versionB.stl]
2023-06-09 Adjusted for tighter fit
    Stems were thickened by around .05mm.
    [cheatbox-project-dbrake-snackboxmicro-kailh-choc-v1.stl]
2023-06-11 FOOTSIE v2.0 Launch
    [micro-xl-footsie-left.stl, micro-xl-footsie-right.stl, og-micro-eco-footsie-left-test-v1.stl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]
2023-06-11 Screwhole tweak
    Allows for tighter fit
2023-06-14 Added detailed dimensions for using printing services
2023-06-15 ChocV2 added for testing
    [cheatbox-project-dbrake-kailh-choc-v2-size11.stl]
2023-06-16 Choc V1 tweaks
    Rolled back to the original fit. A thicker stem version is available for those that want it, but I find the original more comfortable and less likely to pop out from my personal experience. YMMV!
    [cheatbox-project-dbrake-snackboxmicro-kailh-choc-v1-thickerstem.stl, cheatbox-project-dbrake-snackboxmicro-kailh-choc-v1.stl]
2024-03-12 Qanba Gravity D-BRAKE remixes
    [remix-cheatbox-project-dbrake-qanba-gravity-30mm-size11.stl, remix-robear512-dbrake-qanba-gravity-30mm.stl]
2024-03-22 Qanba Gravity 24mm remix added
    [remix-cheatbox-project-dbrake-qanba-gravity-24mm-size11.stl]
2024-07-15 D-BRAKE for Haute42
    [haute42-MT-08CE.stl]
2024-08-20 D-BRAKE for Haute42 G series
    [haute42-MT-08CE.stl]
2024-10-02 D-BRAKE beta for U-Series added
2024-10-02 D-BRAKE beta for U-Series
2024-10-10 D-Brake for U-Series
2024-11-25 B16 Faceplate added
    [cheatboxproject-B16-faceplate-face-down.stl, cheatboxproject-B16-faceplate-face-up.stl]
2025-02-02 alignment tweaks
    [cheatboxproject-B16-faceplate-face-down.stl, cheatboxproject-B16-faceplate-face-up.stl]
2025-02-15 B16 Fest Plate
    [cheatboxproject-B16-festplate.stl]
2025-03-21 GamerFinger 24mm added
2025-07-10 D-BRAKE for Haute42 S-Series
2025-09-05 Sworl Hole Plugs added
    [cheatboxproject-B16-faceplate-fortnite-festival.3mf, sw-plug-above-artwork.stl, sw-plug-below-artwork.stl]
2025-10-26 fixed some mesh errors
    [cheatbox-project-footsie-left.stl, cheatbox-project-footsie-right.stl]
2026-05-29 footsie for keebfighter 02 prototype added
2026-08-14 D-Brake for SWORL launch
    [dbrake-sworl-07mm.stl]
2026-08-16 08mm added
2026-08-28 D-Brake for FlashTap launch
    [dbrake-flashtap24-08mm-CE.stl, dbrake-flashtap24-09mm-CE.stl, dbrake-flashtap30-08mm-CE.stl]
2026-10-08 D-BRAKE for Hori Hayabusa added
    [dbrake-hayabusa-30mm-8.5mm-CE.stl]
